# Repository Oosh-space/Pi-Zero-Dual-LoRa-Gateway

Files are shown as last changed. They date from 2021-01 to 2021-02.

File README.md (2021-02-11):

# Pi Zero Dual LoRa Gateway
Dual LoRa Gateway HAT for the Pi Zero

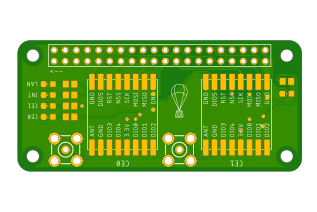
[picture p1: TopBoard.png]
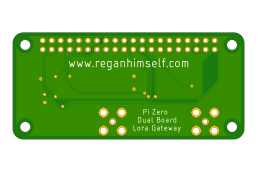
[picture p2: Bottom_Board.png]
 

# Introduction
Here is an attempt at creating a dual lora gateway for the Pi Zero as I wanted something small to track up to two trackers at once. Potentially from my pocket while I am running around a field looking for the trackers!! This board was intended to be used along with Dave Akermans LoRa Gateway software he developed for the Pi in The Sky project (https://github.com/PiInTheSky/lora-gateway.git) 

# Component Requirements 
* 1 x 20x2 pin header (female) 
* 1 x Hope RF LoRa Chip (the 2nd is optional) 
* 1 x SMA connector (the 2nd is optional) 
* 5 x 0805 SMD LEDs and appropriate resistors (optional) 

# Gerbers and boards 
For those of you familiar with board fabricators such as JLCPCB etc there is a gerber file for you to upload to get the board printed to make your own gateway. However boards are also available from my Ko-Fi page here: 

https://ko-fi.com/reganhimself/shop

# Setting up the Gateway
Once you have soldered up the board, you will need to install the LoRa Gateway software on your pi, Daves written a very easy to follow blog post about it here; 

https://www.daveakerman.com/?p=1719

# Support Me

If you found this board useful, why not buy me a coffee! 



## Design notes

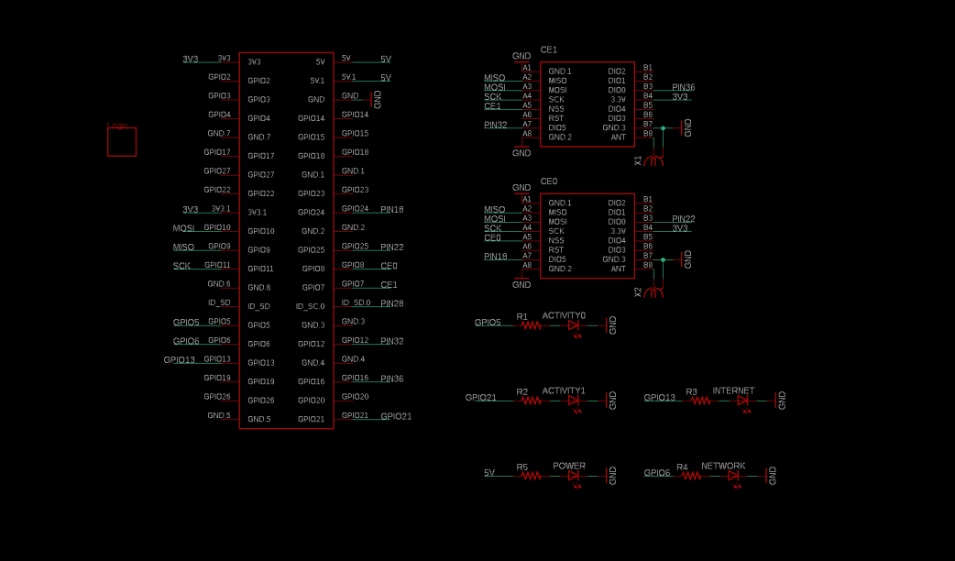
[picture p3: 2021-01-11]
Schematic.png

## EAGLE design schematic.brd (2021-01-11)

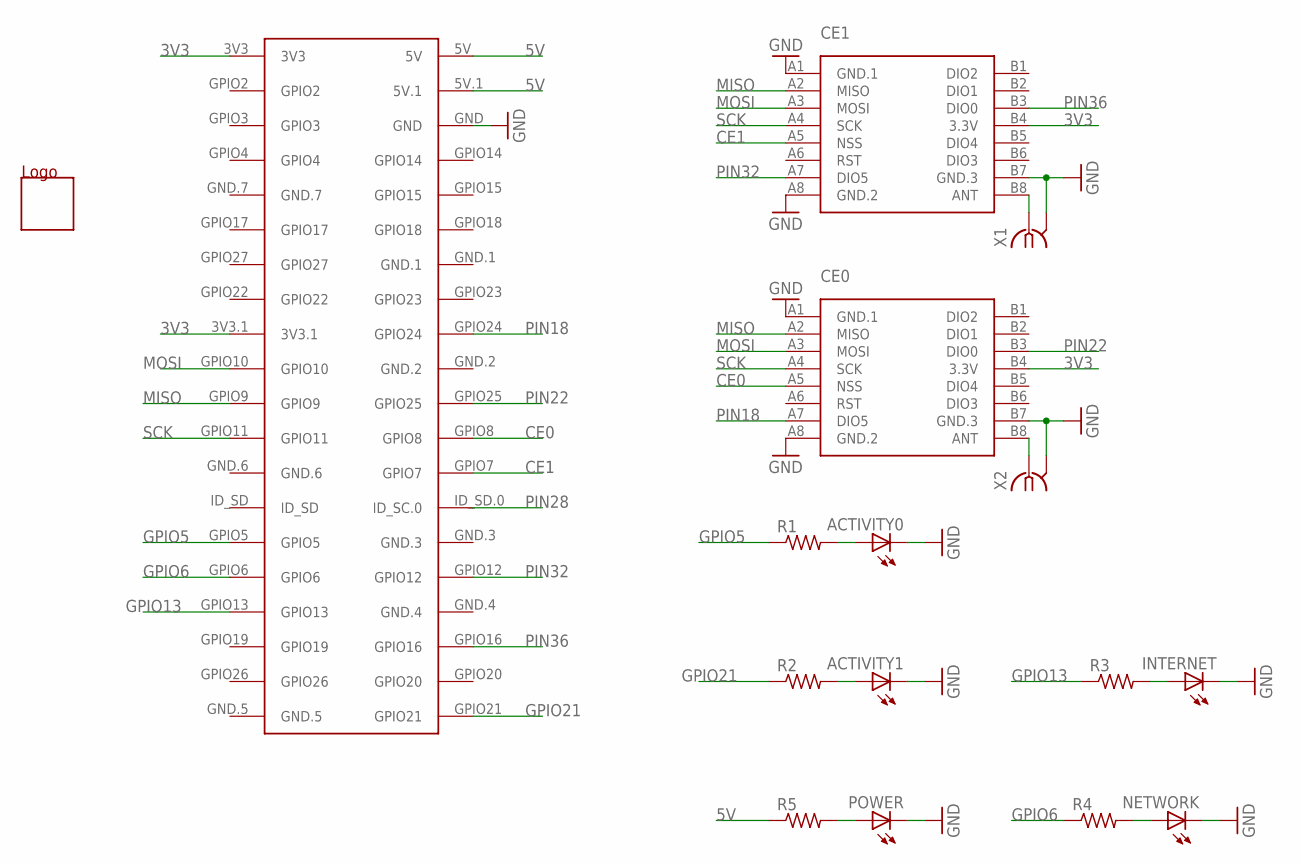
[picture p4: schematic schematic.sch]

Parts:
ACTIVITY0, ACTIVITY1: LEDCHIPLED_0805; CHIPLED_0805
CE0, CE1: WIRELESS-LORA-RFM95W#SMD
INTERNET: LEDCHIPLED_0805; CHIPLED_0805
NETWORK: LEDCHIPLED_0805; CHIPLED_0805
POWER: LEDCHIPLED_0805; CHIPLED_0805
R1, R2, R3, R4, R5: R-US_R0805; R0805
U$1: PIZERO
U$2: REGANLOGO
X1, X2: BU-SMA-V

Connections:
3V3: CE0.B4 (3.3V), CE1.B4 (3.3V), U$1.3V3, U$1.3V3.1
5V: R5.1, U$1.5V, U$1.5V.1
CE0: CE0.A5 (NSS), U$1.GPIO8
CE1: CE1.A5 (NSS), U$1.GPIO7
GND: ACTIVITY0.C, ACTIVITY1.C, CE0.A1 (GND.1), CE0.A8 (GND.2), CE0.B7 (GND.3), CE1.A1 (GND.1), CE1.A8 (GND.2), CE1.B7 (GND.3), INTERNET.C, NETWORK.C, POWER.C, U$1.GND, X1.2, X1.3 (2), X1.4 (2), X1.5 (2), X2.2, X2.3 (2), X2.4 (2), X2.5 (2)
GPIO5: R1.1, U$1.GPIO5
GPIO6: R4.1, U$1.GPIO6
GPIO13: R3.1, U$1.GPIO13
GPIO21: R2.1, U$1.GPIO21
MISO: CE0.A2 (MISO), CE1.A2 (MISO), U$1.GPIO9
MOSI: CE0.A3 (MOSI), CE1.A3 (MOSI), U$1.GPIO10
unnamed: ACTIVITY0.A, R1.2
unnamed: ACTIVITY1.A, R2.2
unnamed: INTERNET.A, R3.2
unnamed: NETWORK.A, R4.2
unnamed: POWER.A, R5.2
unnamed: CE1.B8 (ANT), X1.1
unnamed: CE0.B8 (ANT), X2.1
PIN18: CE0.A7 (DIO5), U$1.GPIO24
PIN22: CE0.B3 (DIO0), U$1.GPIO25
PIN28: U$1.ID_SD.0 (ID_SC.0)
PIN32: CE1.A7 (DIO5), U$1.GPIO12
PIN36: CE1.B3 (DIO0), U$1.GPIO16
SCK: CE0.A4 (SCK), CE1.A4 (SCK), U$1.GPIO11

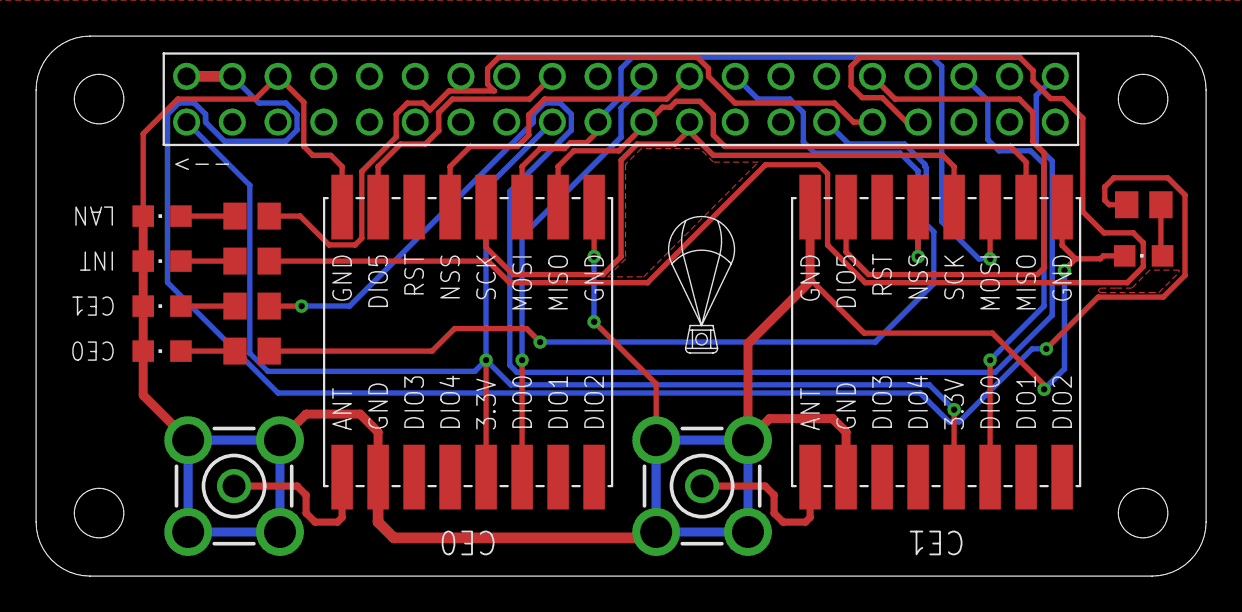
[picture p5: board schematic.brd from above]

Board: 2 copper layers, 65.0 x 30.0 mm, 16 parts (0 on the bottom side), 23 nets.

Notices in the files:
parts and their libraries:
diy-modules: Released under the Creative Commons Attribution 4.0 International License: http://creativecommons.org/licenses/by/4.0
